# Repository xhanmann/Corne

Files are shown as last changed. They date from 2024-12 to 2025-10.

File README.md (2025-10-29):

# Budget Wireless Corne Keyboard Build

A DIY wireless split keyboard based on the Corne layout, built for approximately $25 USD. This project uses a ProMicro clone with nrf52840 chip, making it a cost-effective alternative to traditional wireless split keyboard builds.

## Features
- Fully wireless using Bluetooth
- Split ergonomic design (Corne layout)
- Low profile design for portability
- Battery-powered with power switch
- ZMK firmware
- Estimated battery life: 1+ month

## Bill of Materials

| Component | Quantity | Cost (USD) | Link |
|---|---|---|---|
| Controller boards (ProMicro nrf52840) | 2 | 6.82 | [AliExpress](https://a.aliexpress.com/_EIV3vwY) |
| Batteries | 2 | 4.20 | [AliExpress](https://a.aliexpress.com/_Eynt9TK) |
| Mechanical Switches | 50 | 7.47 | [AliExpress](https://a.aliexpress.com/_EGhMxEC) |
| Keycaps | Set | 3.79 | [Option 1](https://a.aliexpress.com/_EzQyNtA) / [Option 2](https://a.aliexpress.com/_EH8mNqs) |
| Diodes (1N4148) | 100 | 0.85 | [AliExpress](https://a.aliexpress.com/_EwZoG2G) |
| Slide Switches | 2 | 0.11 | |
| 3D Printed Parts | Set | 1.80 | Files provided |

**Total Cost**: $25.04 (excluding wires and screws)

## Current Keymap







## Build Instructions

### Prerequisites
- Basic soldering skills
- Access to a 3D printer
- Basic understanding of keyboard firmware

### Case Assembly
1. Print the case files (STL files provided in `3DFiles` directory)
2. Note: You may need to adjust the:
   - Battery compartment size
   - Slide switch holes

### Wiring
1. Wire switches in a matrix configuration
2. Connect diodes:
   - Direction matters (black line indicates cathode)
   - Use diode legs for the rows
   - Use separate wires for columns
3. Keep wiring clear of screw holes
4. Connect the battery:
   - GND to GND pin
   - Positive to one of the side legs on the slide switch
   - Middle pin of the slide switch to the RAW pin

### Pin Connections for Rows and Columns
The matrix configuration uses GPIO pins on the nRF52840 Pro Micro clone. Below are the connections:

pinout

#### Rows (Connected to `row-gpios`):
- Row 0: Pin 20
- Row 1: Pin 19
- Row 2: Pin 18
- Row 3: Pin 15

#### Columns (Connected to `col-gpios`):
- Column 0: Pin 6
- Column 1: Pin 7
- Column 2: Pin 9
- Column 3: Pin 8
- Column 4: Pin 16
- Column 5: Pin 14

These pins are defined in the firmware and are configured for GPIO matrix scanning.

### Firmware Setup
This keyboard uses ZMK firmware. The left half acts as the main controller that connects to your device.

To flash the firmware:
1. Double press the reset button
2. Board will appear as mass storage device
3. Flash the appropriate firmware file

If you forgot the keyboard from your device and can't reconnect:
1. Flash the `settings_reset-nice_nano_v2-zmk.uf2` file
2. Reflash the regular firmware
3. Pair

## Repository Structure
```
├── .github/workflows/
│   └── build.yml
├── 3DFiles/
│   ├── Case_Left.stl
│   ├── Case_Right.stl
│   └── PlateCorne.stl
├── config/
│   ├── boards/shields/corne/
│   │   ├── corne_left.conf
│   │   ├── corne_left.overlay
│   │   ├── corne_right.conf
│   │   ├── corne_right.overlay
│   │   ├── corne.conf
│   │   ├── corne.dtsi
│   │   ├── Kconfig.defconfig
│   │   └── Kconfig.shield
│   ├── corne.keymap
│   └── west.yml
├── firmware/
│   ├── corne_left-nice_nano_v2-zmk.uf2
│   ├── corne_right-nice_nano_v2-zmk.uf2
│   └── settings_reset-nice_nano_v2-zmk.uf2
└── zephyr/
    ├── module.yml
    └── build.yaml
```

## Known Issues
- Left side case may have warping issues if battery swells
- Slide switch holes may need adjustment based on your components

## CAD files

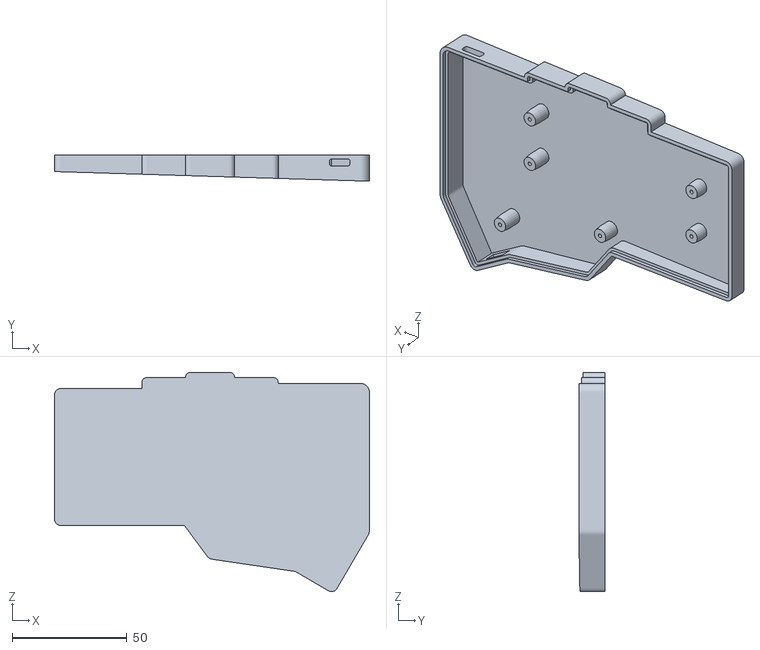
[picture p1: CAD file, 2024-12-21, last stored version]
3DFiles/Case_Right.stl
137.1 x 11.5 x 95.4

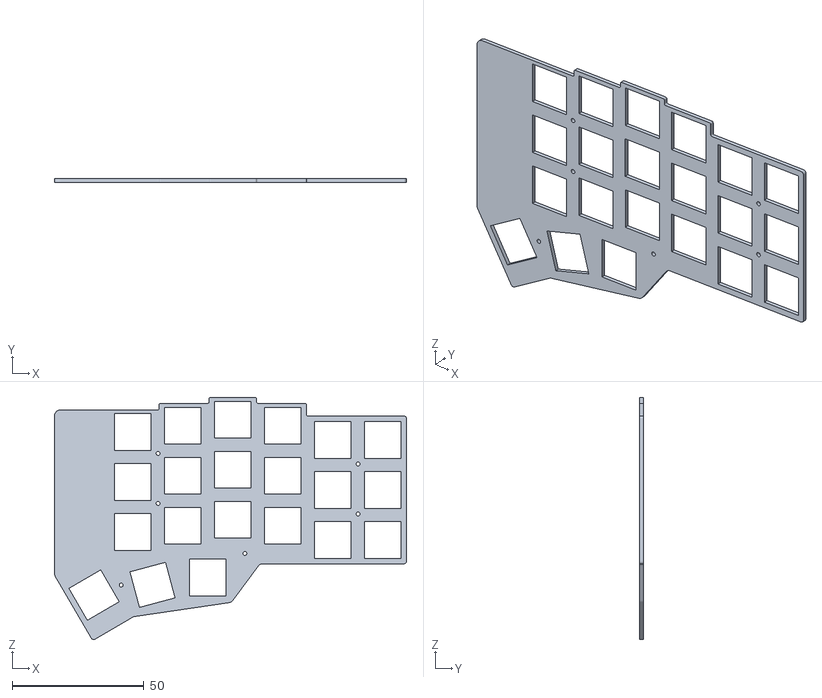
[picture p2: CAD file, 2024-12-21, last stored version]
3DFiles/PlateCorne.stl
133.8 x 1.35 x 92.0

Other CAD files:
3DFiles/Case_Left.stl

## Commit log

2024-12-21 3d files and keymap update
    [Case_Left.stl, Case_Right.stl, PlateCorne.stl]
2025-10-23 Configure pull-up and pull-down for I2C and SPI
    Added bias-pull-up and bias-pull-down configurations for I2C and SPI in corne.dtsi.
2025-10-24 Update I2C configuration in corne_left.overlay
2025-10-24 Configure I2C for SSD1306 display
    Added I2C configuration for SSD1306 display.
2025-10-24 Clean up board configurations in build.yaml
    Removed unused board and shield configurations for nice_nano_v2.
2025-10-26 Modify col-gpios to use pull-down resistors
    Updated column GPIO settings to include pull-down resistors.
2025-10-27 Change OLED display I2C address to 0x3C
    Updated I2C address for the OLED display from 0x3D to 0x3C.
2025-10-27 Fix SSD1306 I2C address in corne_right.overlay
2025-10-28 Change WS2812 data pin from 0 to 08
2025-10-29 Change I2C SDA and SCL pin assignments
    Updated I2C pin selections for corne.dtsi.
2025-10-29 Change SPI MOSI pin selection in corne.dtsi
    Updated SPI MOSI pin selection for default and sleep configurations.
2025-10-29 Fix pin assignments for rows and columns
    Updated pin assignments for rows and columns in the README.
2026-07-22 fix: Update corne.conf with proper nRF52840 I2C address and clean up WS2812 config
2026-07-22 fix: Correct WS2812 SPI MOSI pin from P0.0 to P0.8 for nRF52840
2026-07-22 Add nrfmicro_v2 board support for nrf52840 builds
2026-07-22 Fix: Replace nrfmicro_v2 with nrfmicro board name for ZMK compatibility
2026-07-22 Fix: Add nrfmicro to shield requirements to support both nice_nano_v2 and nrfmicro boards
2026-07-22 Update board configuration in build.yaml
2026-07-23 Update board references in build.yaml
2026-07-23 Fix board name typo in build.yaml
2026-07-23 Update board paths in build.yaml for ZMK
2026-07-23 Fix board name typos in build.yaml
